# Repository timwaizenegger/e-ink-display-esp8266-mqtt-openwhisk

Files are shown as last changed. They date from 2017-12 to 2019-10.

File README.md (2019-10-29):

# e-ink-display-esp8266-mqtt-openwhisk
This repo contains code to control an e-ink module, connected to a WeMos D1 ESP8266 chip, from cloud functions on openWhisk using MQTT

## Overview

  e-ink display module --> ESP8266 --> MQTT --> Whisk actions

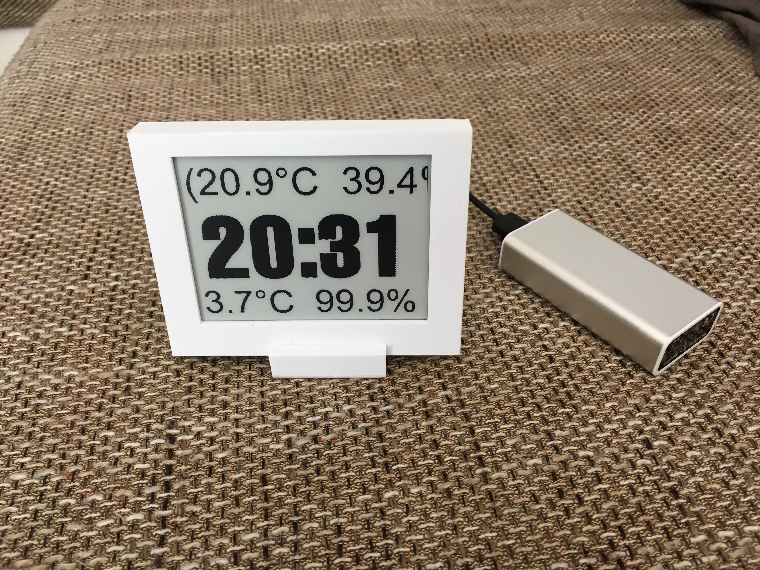
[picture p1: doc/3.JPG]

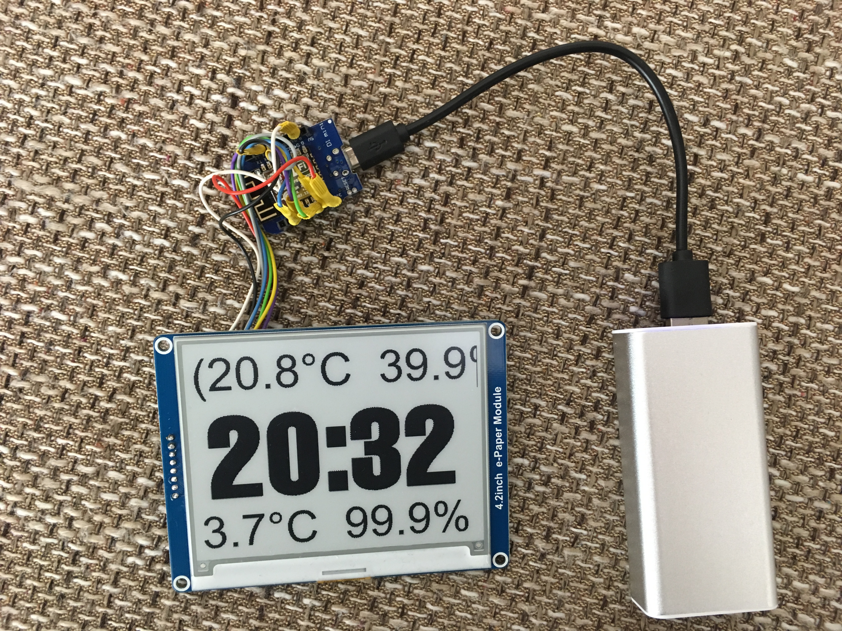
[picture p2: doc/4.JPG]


### Parts

You need only 2 parts to build a display like this yourself:

* WeMos D1 microcontroller or equiv. ESP8266 chip [https://www.ebay.com/itm/D1-Mini-NodeMcu-4M-bytes-Lua-WIFI-Development-Board-ESP8266-by-WeMos](https://www.ebay.com/itm/D1-Mini-NodeMcu-4M-bytes-Lua-WIFI-Development-Board-ESP8266-by-WeMos)
The WeMos D1 has USB built in which makes it very easy to program/power.

* E-Ink display. I used a Waveshare 4.2in display with SPI connection. [https://www.ebay.com/itm/4-2inch-E-Ink-Display-400x300-E-paper-Module-SPI-for-Raspberry-Pi-Arduino-STM32](https://www.ebay.com/itm/4-2inch-E-Ink-Display-400x300-E-paper-Module-SPI-for-Raspberry-Pi-Arduino-STM32)
Different brands and different conections may not be compatible with the Software in this repo.

* The power supply/regulator is optional. You can power it from USB.

## Arduino code for ESP8266 wifi microcontroller

* [arduino-esp8266-eink-display/](arduino-esp8266-eink-display/)

The arduino code runs on any generic ESP8266 module; here I use a WeMos D1. It has an included 5V->3.3V regulator and USB<>Serial converter for programming. 

It can be powered from USB and its 3.3V output supplies enough for the e-ink module. The photos also show a separate 3.3V regulator so that ESP and display can be powered externally by 4-20V.

The arduino code connects to a wifi then to an mqtt broker. There, it waits for messages containing pixel data as a byte array. The entire mqtt message payload must be pixel data black/white with 1 bit per pixel. Each byte/char represents 8 pixels. 

The Whisk actions will generate this byte array. So on the MQTT channel, we need support for a byte data-type and can't use pure Strings.

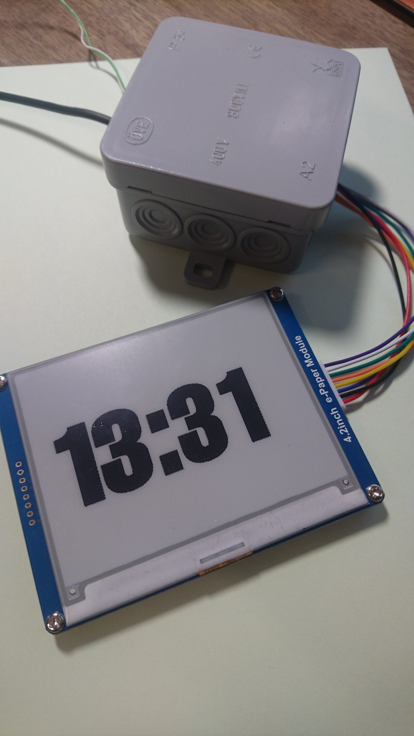
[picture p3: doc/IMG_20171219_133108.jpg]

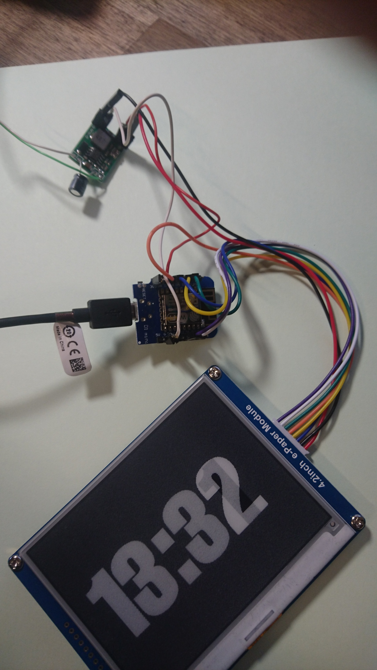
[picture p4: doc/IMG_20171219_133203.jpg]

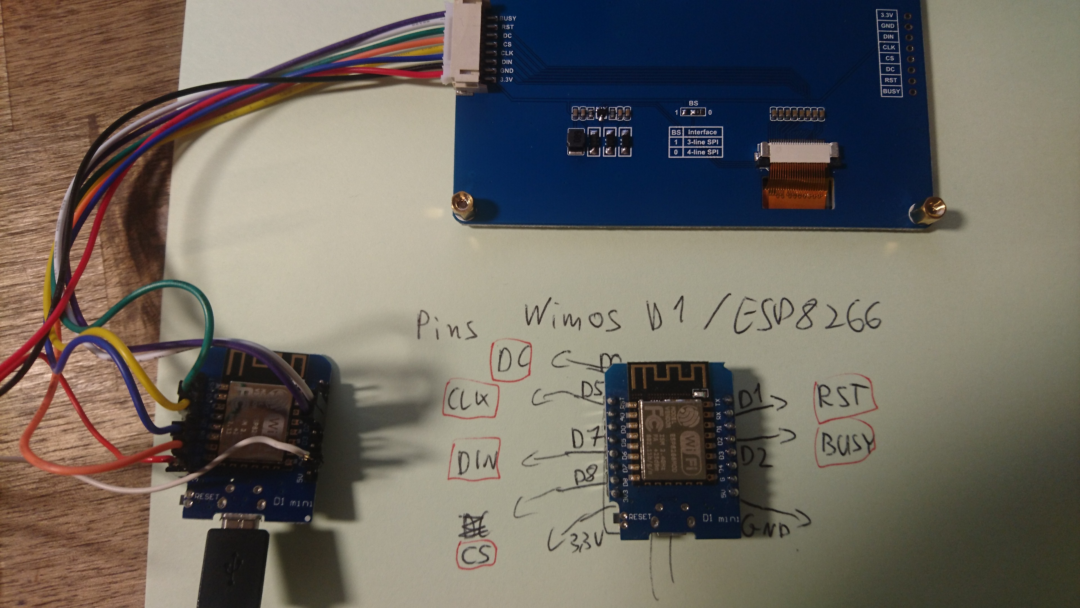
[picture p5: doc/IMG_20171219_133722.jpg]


### Compiling Arduino code

* You need the ESP8266 "Board" plugin installed in your Arduino IDE
* Select the WeMos D1 board type and USB port
* Some libraries need to be installed acc. to include statements. You can use the Arduino library manager

#### Waveshare
The code uses some parts of the example library from Waveshare [https://www.waveshare.com/wiki/4.3inch_e-Paper_UART_Module](https://www.waveshare.com/wiki/4.3inch_e-Paper_UART_Module)

Only the interface to the display module is used and a whole frame (from mqtt) is always drawn at once. For these displays, the ESP8266 has enough memory to hold multiple full monochrome frames.

The library also includes basic drawing and text rendering directly on the ESP. For smaller microcontrollers, it has a simple partial framebuffer support.

# 3D printed case

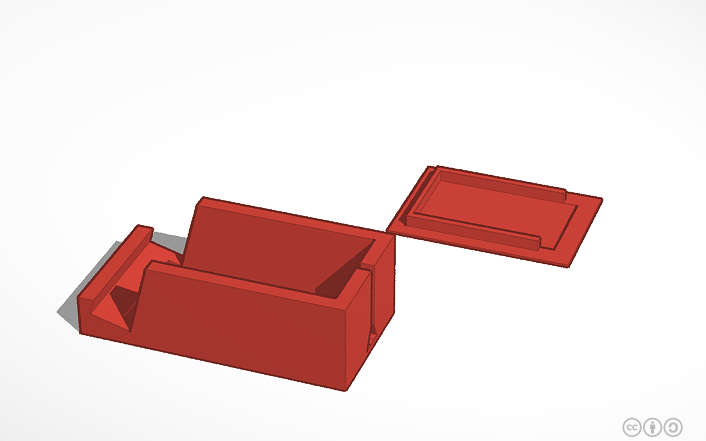
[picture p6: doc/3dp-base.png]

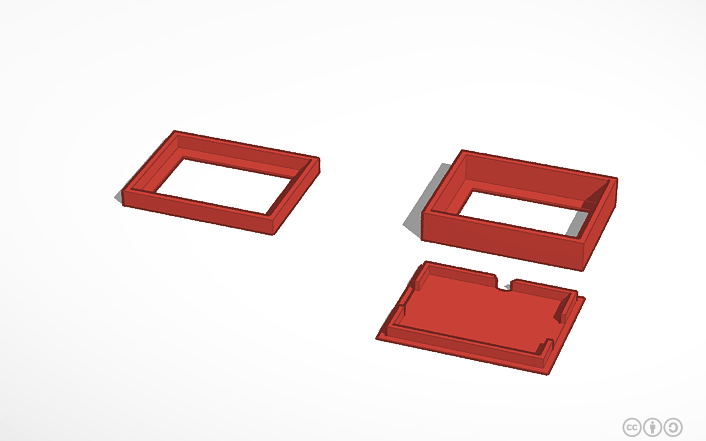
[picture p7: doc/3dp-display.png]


You can find `STL` files for 3D printing the base/display case in `3d-print/`.

The designs can also be edited online on tinkercad.com:

* https://www.tinkercad.com/things/0IOFBVQCBK1-eink-clock-base/editv2
* https://www.tinkercad.com/things/iZ5w3NCEkOe-eink-clock1/editv2

# IBM Cloud MQTT Broker

### Prepare the service

1) Go to the Catalog and provision a `Internet of Things Platform` instance with the "Free" plan.
1) Launch the dashboard, go into Settings
1) Give it a nice Name if you want to 
1) Go into "Connection Security" and set the Security Level to "TLS Optional". This allows us connection without TLS

### Add the device
1) Go to add a device, create/select a device type. Doesn't matter what you call it
1) Give the device a name/ID
1) Skip the metadata
1) Give it a password/security token

- How to connect to this broker with the Arduino libraries:
  - https://developer.ibm.com/recipes/tutorials/ibm-iot-and-arduino/
  - Add the display/Arduino as a "device"
  - Add whisk as a "Application" so that it can send messages to devices
    - Go to "Apps" and create an APi key there
    - https://www.ibm.com/support/knowledgecenter/SSQP8H/iot/platform/applications/mqtt.html

# Whisk actions

The two whisk actions here provide clock-image rendering, and sending images to the display.
As a whisk secuence, together with a periodic trigger, they create the live clock display.

Between the two actions, the rendered image is exchanged within the messages as base64. This limits the possible image size depending on what limit we have in Whisk. Images here are few KBs, 15KB max.

## python send mqtt image

* [whisk_python_sendmqttimage/](whisk_python_sendmqttimage/)

This action is written in python and uses the paho mqtt library to send the pixel data to the esp. The action accepts a base64 encoded image (any format; png is used here) and brings it into the correct format for the e-ink display. Inside the action, the mqtt connection is configured.

## js make clock image

* [whisk_js_makeclock/](whisk_js_makeclock/)

This action uses the js library "Jimp" to render a PNG image with the current time. You can copy the resulting image-string into a browser address bar to preview the resulting image.

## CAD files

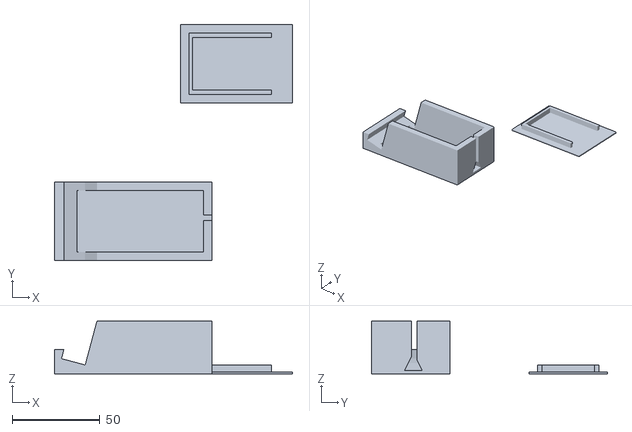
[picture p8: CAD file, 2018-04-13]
3dprint/eink clock - base.stl
136.0 x 135.0 x 30.0

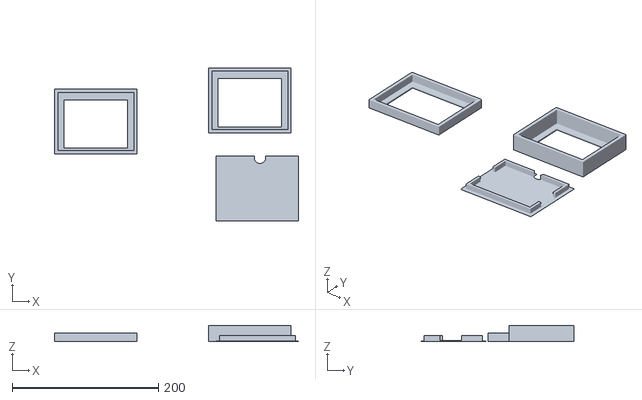
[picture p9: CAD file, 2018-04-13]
3dprint/eink clock - display.stl
334.0 x 210.0 x 22.0

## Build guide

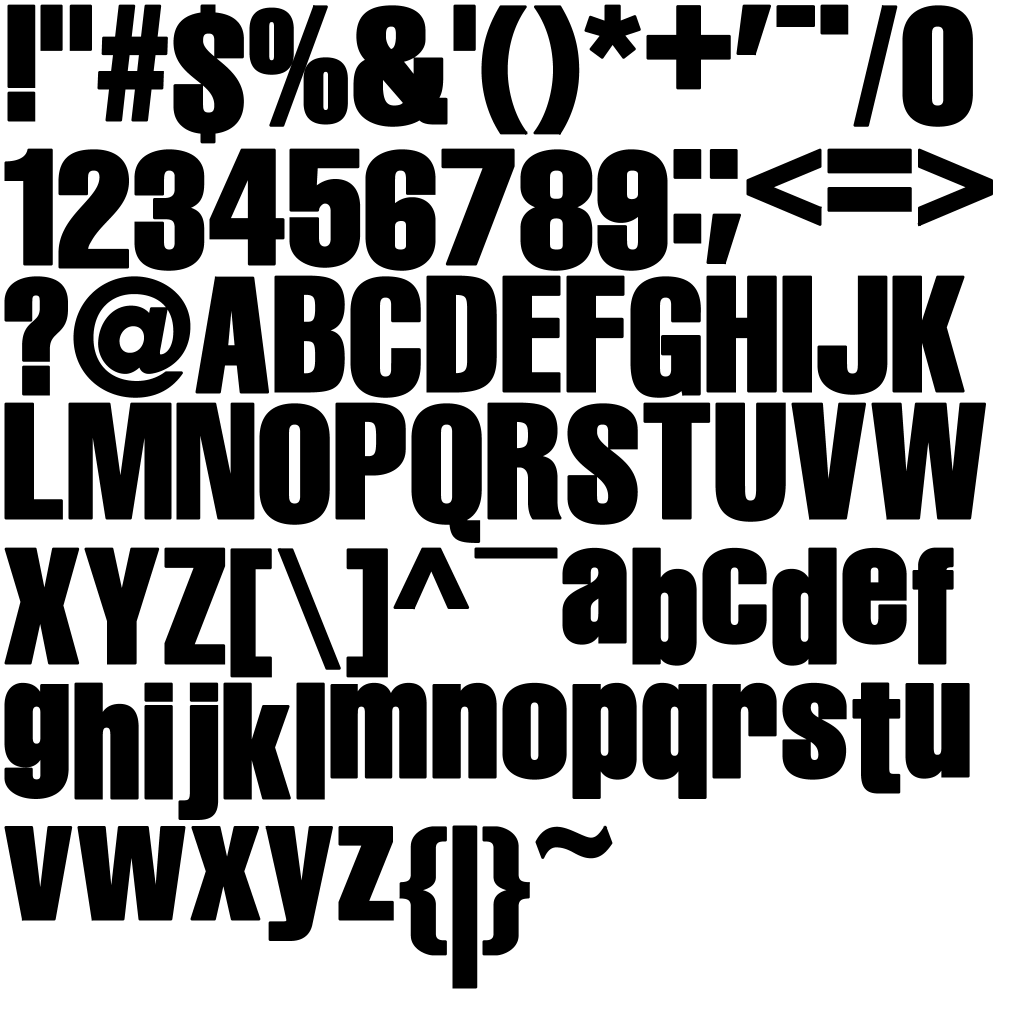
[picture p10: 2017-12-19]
whisk_js_makeclock/font-hel.png

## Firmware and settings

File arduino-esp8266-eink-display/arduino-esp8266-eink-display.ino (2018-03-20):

#include "epd4in2.h"
#include "epdpaint.h"
/*

  TCL IOT script
  Tim Waizenegger (c) 2018
  ESP8266 on arduino, pusub mqtt client, eink display module

https://github.com/timwaizenegger/e-ink-display-esp8266-mqtt-openwhisk

E-Ink display. I used a Waveshare 4.2in display with SPI connection. https://www.ebay.com/itm/4-2inch-E-Ink-Display-400x300-E-paper-Module-SPI-for-Raspberry-Pi-Arduino-STM32 Different brands and different conections may not be compatible with the Software 

*/


// NOTE: we need to increse the max packet size for our mqtt lib. its too small for these image messages
//   have to define this in /home/tim/Arduino/libraries/PubSubClient/src/PubSubClient.h
//   We need to figure out how to set these vars here...
//   this is the max length of our pixel data

// #define MQTT_MAX_PACKET_SIZE 15100 


#include <ESP8266WiFi.h>
#include <PubSubClient.h>
extern "C" {
#include "user_interface.h"
}

#define COLORED     0
#define UNCOLORED   1



#define SLEEPTIME 50000
unsigned long previousMillis = 0;


// And here we have triple-WIFI support :)
const char* ssid1 = "wifi name 1";
const char* password1 = "pw";

const char* ssid2 = "a";
const char* password2 = "a";

const char* ssid3 = "a-a-a";
const char* password3 = "a";

const char* mq_id = "mqttid";
const char* mq_authtoken = "password or token";
const char* mq_serverUrl = "example.com";


// topic is in multiple places in the code...
// const char* mq_topic = "displaychannel-eink2/byte-image-data"


WiFiClient espClient;
PubSubClient client(mq_serverUrl, 1883, espClient);



////////////////////////////////////////////////////////////////////////////////
////////////////////////////////////////////////////////////////////////////////
// ARDUINO API


void setup() {
  // put your setup code here, to run once:
  Serial.begin(57600);
  Serial.println("Begin e-Paper display");

  //draw_status_display("Start...", "mqtt esp8266 eink display");

  draw_status_display("starting", "connecting to wifi network");
  setup_wifi();
  client.setServer(mq_serverUrl, 1883);
  client.setCallback(callback);



  Serial.println("starting ...");

}

void loop() {


  if (!client.connected()) {
    reconnect();
  }
  client.loop();




  // update the display regularly
  unsigned long currentMillis = millis();
  if (currentMillis - previousMillis >= SLEEPTIME) {
    previousMillis = currentMillis;

    Serial.println("ping");

  }

}


////////////////////////////////////////////////////////////////////////////////
////////////////////////////////////////////////////////////////////////////////
// MQTT WIFI

void setup_wifi() {


  //draw_status_display("WIFI", "connecting to WIFI");

  // We start by connecting to a WiFi network
  Serial.println();
  Serial.print("Connecting to ");

  while (WiFi.status() != WL_CONNECTED) {

    Serial.println(ssid1);
    WiFi.begin(ssid1, password1);
    for (int i = 0; i < 200; i++) {
      delay(100);
      Serial.print(".");
      Serial.print(WiFi.status());
      if (WiFi.status() == WL_CONNECTED) {
        break;
      }
    }
    if (WiFi.status() == WL_CONNECTED) {
      break;
    }
    Serial.println(ssid2);
    WiFi.begin(ssid2, password2);
    for (int i = 0; i < 200; i++) {
      delay(100);
      Serial.print(".");
      Serial.print(WiFi.status());
      if (WiFi.status() == WL_CONNECTED) {
        break;
      }
    }
    if (WiFi.status() == WL_CONNECTED) {
      break;
    }
    Serial.println(ssid3);
    WiFi.begin(ssid3, password3);
    for (int i = 0; i < 200; i++) {
      delay(100);
      Serial.print(".");
      Serial.print(WiFi.status());
      if (WiFi.status() == WL_CONNECTED) {
        break;
      }
    }



  }
  delay(500);
  Serial.println("");
  Serial.println("WiFi connected");
  Serial.println("IP address: ");
  Serial.println(WiFi.localIP());


  draw_status_display("wifi connection", "online");
}




void callback(char* topic, byte* payload, unsigned int length) {
  Serial.print("Message arrived [");
  Serial.print(topic);
  Serial.print("] ");

  if (strcmp(topic, "displaychannel-eink2/byte-image-data") == 0) {

    const int buffer_len = 15100;

    int copy_length = length;
    if (length > buffer_len) copy_length = buffer_len;

    Serial.println();
    Serial.println("Copying byte image data. Size of msg:");
    Serial.println(length);
    Serial.println("buffer length is:");
    Serial.println(buffer_len);

    unsigned char *image = new unsigned char[buffer_len];

    for (int i = 0; i < copy_length; i++) {
      //Serial.print((char)payload[i]);
      image[i] = payload[i];

    }
    Serial.println("Sending bytes to eink display");
    draw_data(image);

  }

}

void reconnect() {
  // Loop until we're reconnected
  while (!client.connected()) {
    Serial.print("Attempting MQTT connection...");

    draw_status_display("MQTT broker", "connecting ...");
    // Attempt to connect
    if (client.connect(mq_id, mq_id, mq_authtoken)) {
      Serial.println("connected");

      draw_status_display("MQTT connected!", "waiting for MQTT pixel data...");
      // ... and resubscribe
      client.subscribe("displaychannel-eink2/byte-image-data");
    } else {
      draw_status_display("MQTT", "MQTT connection failed");
      Serial.print("failed, rc=");
      Serial.print(client.state());
      Serial.println(" try again in 5 seconds");
      // Wait 5 seconds before retrying
      delay(5000);
    }
  }
}












////////////////////////////////////////////////////////////////////////////////
////////////////////////////////////////////////////////////////////////////////
// EINK DISPLAY
void draw_status_display(char* title, char* message) {
  Serial.println("drawing status display message");
  Serial.println(title);
  Serial.println(message);

  const int buffer_len = 15100;
  unsigned char *image = new unsigned char[buffer_len];

  Paint paint(image, 400, 300);
  paint.Clear(UNCOLORED);


  paint.DrawStringAt(5, 5, title, &Font24, COLORED);
  paint.DrawStringAt(0, 100, message, &Font16, COLORED);


  Epd epd;
  if (epd.Init() != 0) {
    Serial.println("e-Paper init failed");
    return;
  }
  epd.ClearFrame();
  epd.DisplayFrame(paint.GetImage());
  delete(image);
  epd.Sleep();


}




void draw_data(unsigned char *image) {
  Serial.println("drawing display from bytes");

  Epd epd;
  if (epd.Init() != 0) {
    Serial.println("e-Paper init failed");
    return;
  }
  epd.ClearFrame();
  epd.DisplayFrame(image);
  delete(image);
  epd.Sleep();
}

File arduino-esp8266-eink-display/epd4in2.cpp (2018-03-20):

/**
 *  @filename   :   epd4in2.cpp
 *  @brief      :   Implements for Dual-color e-paper library
 *  @author     :   Yehui from Waveshare
 *
 *  Copyright (C) Waveshare     August 10 2017
 *
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
 * THE SOFTWARE IS PROVIDED "AS IS", WITHOUT WARRANTY OF ANY KIND, EXPRESS OR
 * IMPLIED, INCLUDING BUT NOT LIMITED TO THE WARRANTIES OF MERCHANTABILITY,
 * FITNESS OR A PARTICULAR PURPOSE AND NONINFRINGEMENT. IN NO EVENT SHALL THE
 * AUTHORS OR COPYRIGHT HOLDERS BE LIABLE FOR ANY CLAIM, DAMAGES OR OTHER
 * LIABILITY WHETHER IN AN ACTION OF CONTRACT, TORT OR OTHERWISE, ARISING FROM,
 * OUT OF OR IN CONNECTION WITH THE SOFTWARE OR THE USE OR OTHER DEALINGS IN
 * THE SOFTWARE.
 */

#include <stdlib.h>
#include <Arduino.h>
#include "epd4in2.h"

Epd::~Epd() {
};

Epd::Epd() {
    reset_pin = RST_PIN;
    dc_pin = DC_PIN;
    cs_pin = CS_PIN;
    busy_pin = BUSY_PIN;
    width = EPD_WIDTH;
    height = EPD_HEIGHT;
};

int Epd::Init(void) {
    /* this calls the peripheral hardware interface, see epdif */
    if (IfInit() != 0) {
        return -1;
    }
    /* EPD hardware init start */
    Reset();
    SendCommand(POWER_SETTING);
    SendData(0x03);                  // VDS_EN, VDG_EN
    SendData(0x00);                  // VCOM_HV, VGHL_LV[1], VGHL_LV[0]
    SendData(0x2b);                  // VDH
    SendData(0x2b);                  // VDL
    SendData(0xff);                  // VDHR
    SendCommand(BOOSTER_SOFT_START);
    SendData(0x17);
    SendData(0x17);
    SendData(0x17);                  //07 0f 17 1f 27 2F 37 2f
    SendCommand(POWER_ON);
    WaitUntilIdle();
    SendCommand(PANEL_SETTING);
    SendData(0xbf);    // KW-BF   KWR-AF  BWROTP 0f
    SendData(0x0b);
    SendCommand(PLL_CONTROL);
    SendData(0x3c);        // 3A 100HZ   29 150Hz 39 200HZ  31 171HZ
    /* EPD hardware init end */
    return 0;
}

/**
 *  @brief: basic function for sending commands
 */
void Epd::SendCommand(unsigned char command) {
    DigitalWrite(dc_pin, LOW);
    SpiTransfer(command);
}

/**
 *  @brief: basic function for sending data
 */
void Epd::SendData(unsigned char data) {
    DigitalWrite(dc_pin, HIGH);
    SpiTransfer(data);
}

/**
 *  @brief: Wait until the busy_pin goes HIGH
 */
void Epd::WaitUntilIdle(void) {
    while(DigitalRead(busy_pin) == 0) {      //0: busy, 1: idle
        DelayMs(100);
    }      
}

/**
 *  @brief: module reset. 
 *          often used to awaken the module in deep sleep, 
 *          see Epd::Sleep();
 */
void Epd::Reset(void) {
    DigitalWrite(reset_pin, LOW);
    DelayMs(200);
    DigitalWrite(reset_pin, HIGH);
    DelayMs(200);   
}

/**
 *  @brief: transmit partial data to the SRAM
 */
void Epd::SetPartialWindow(const unsigned char* buffer_black, int x, int y, int w, int l) {
    SendCommand(PARTIAL_IN);
    SendCommand(PARTIAL_WINDOW);
    SendData(x >> 8);
    SendData(x & 0xf8);     // x should be the multiple of 8, the last 3 bit will always be ignored
    SendData(((x & 0xf8) + w  - 1) >> 8);
    SendData(((x & 0xf8) + w  - 1) | 0x07);
    SendData(y >> 8);        
    SendData(y & 0xff);
    SendData((y + l - 1) >> 8);        
    SendData((y + l - 1) & 0xff);
    SendData(0x01);         // Gates scan both inside and outside of the partial window. (default) 
    DelayMs(2);
    SendCommand(DATA_START_TRANSMISSION_2);
    if (buffer_black != NULL) {
        for(int i = 0; i < w  / 8 * l; i++) {
            SendData(buffer_black[i]);  
        }  
    } else {
        for(int i = 0; i < w  / 8 * l; i++) {
            SendData(0x00);  
        }  
    }
    DelayMs(2);
    SendCommand(PARTIAL_OUT);  
}

/**
 *  @brief: set the look-up table
 */
void Epd::SetLut(void) {
    unsigned int count;     
    SendCommand(LUT_FOR_VCOM);                            //vcom
    for(count = 0; count < 44; count++) {
        SendData(lut_vcom0[count]);
    }
    
    SendCommand(LUT_WHITE_TO_WHITE);                      //ww --
    for(count = 0; count < 42; count++) {
        SendData(lut_ww[count]);
    }   
    
    SendCommand(LUT_BLACK_TO_WHITE);                      //bw r
    for(count = 0; count < 42; count++) {
        SendData(lut_bw[count]);
    } 

    SendCommand(LUT_WHITE_TO_BLACK);                      //wb w
    for(count = 0; count < 42; count++) {
        SendData(lut_bb[count]);
    } 

    SendCommand(LUT_BLACK_TO_BLACK);                      //bb b
    for(count = 0; count < 42; count++) {
        SendData(lut_wb[count]);
    } 
}

/**
 * @brief: refresh and displays the frame
 */
void Epd::DisplayFrame(const unsigned char* frame_buffer) {
    SendCommand(RESOLUTION_SETTING);
    SendData(width >> 8);        
    SendData(width & 0xff);
    SendData(height >> 8);
    SendData(height & 0xff);

    SendCommand(VCM_DC_SETTING);
    SendData(0x12);                   

    SendCommand(VCOM_AND_DATA_INTERVAL_SETTING);
    SendCommand(0x97);    //VBDF 17|D7 VBDW 97  VBDB 57  VBDF F7  VBDW 77  VBDB 37  VBDR B7

    if (frame_buffer != NULL) {
        SendCommand(DATA_START_TRANSMISSION_1);
        for(int i = 0; i < width / 8 * height; i++) {
            SendData(0xFF);      // bit set: white, bit reset: black
        }
        DelayMs(2);
        SendCommand(DATA_START_TRANSMISSION_2); 
        for(int i = 0; i < width / 8 * height; i++) {
            SendData(pgm_read_byte(&frame_buffer[i]));
        }  
        DelayMs(2);                  
    }

    SetLut();

    SendCommand(DISPLAY_REFRESH); 
    DelayMs(100);
    WaitUntilIdle();
}

/**
 * @brief: clear the frame data from the SRAM, this won't refresh the display
 */
void Epd::ClearFrame(void) {
    SendCommand(RESOLUTION_SETTING);
    SendData(width >> 8);
    SendData(width & 0xff);
    SendData(height >> 8);        
    SendData(height & 0xff);

    SendCommand(DATA_START_TRANSMISSION_1);           
    DelayMs(2);
    for(int i = 0; i < width / 8 * height; i++) {
        SendData(0xFF);  
    }  
    DelayMs(2);
    SendCommand(DATA_START_TRANSMISSION_2);           
    DelayMs(2);
    for(int i = 0; i < width / 8 * height; i++) {
        SendData(0xFF);  
    }  
    DelayMs(2);
}

/**
 * @brief: This displays the frame data from SRAM
 */
void Epd::DisplayFrame(void) {
    SetLut();
    SendCommand(DISPLAY_REFRESH); 
    DelayMs(100);
    WaitUntilIdle();
}
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
